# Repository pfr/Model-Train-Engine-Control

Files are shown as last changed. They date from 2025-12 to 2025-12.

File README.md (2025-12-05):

# Model-Train-Engine-Control
If you're a DIYer who enjoys model trains and hobbiest level electronics, and would like to convert your model train engines to radio control and battery power, then this material is for you.

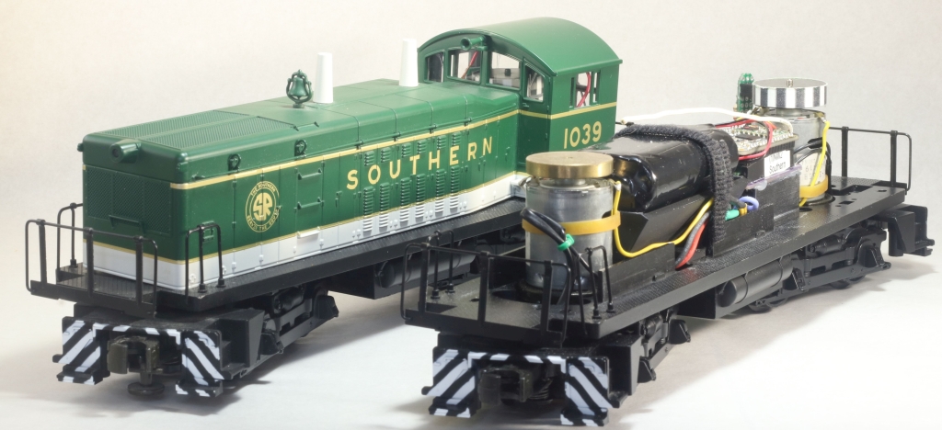
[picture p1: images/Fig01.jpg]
.

Code and other material here was created by me to convert my O scale engines to radio control and battery power.  Seen above is a 1999 MTH NW-2 (https://www.mthtrains.com/products/30-2157-1), one of my smaller engines, with control logic I created and LiPo battery power that can run the engine for hours.  With this accomplishment I'm certain the remainder of my O scale engines can be converted similarly.  There's enough information here to support your doing the same kind of conversions: all of my supporting code, KiCAD design files for a custom PCB, and FreeCAD  design files for 3D printed parts.  

An article on this effort will appear in an upcoming issue of Model Railroader Magazine (https://www.trains.com/mrr/) in early 2026. 

2025 12 05: A reasonably detailed instruction manual for the material here will follow soon.

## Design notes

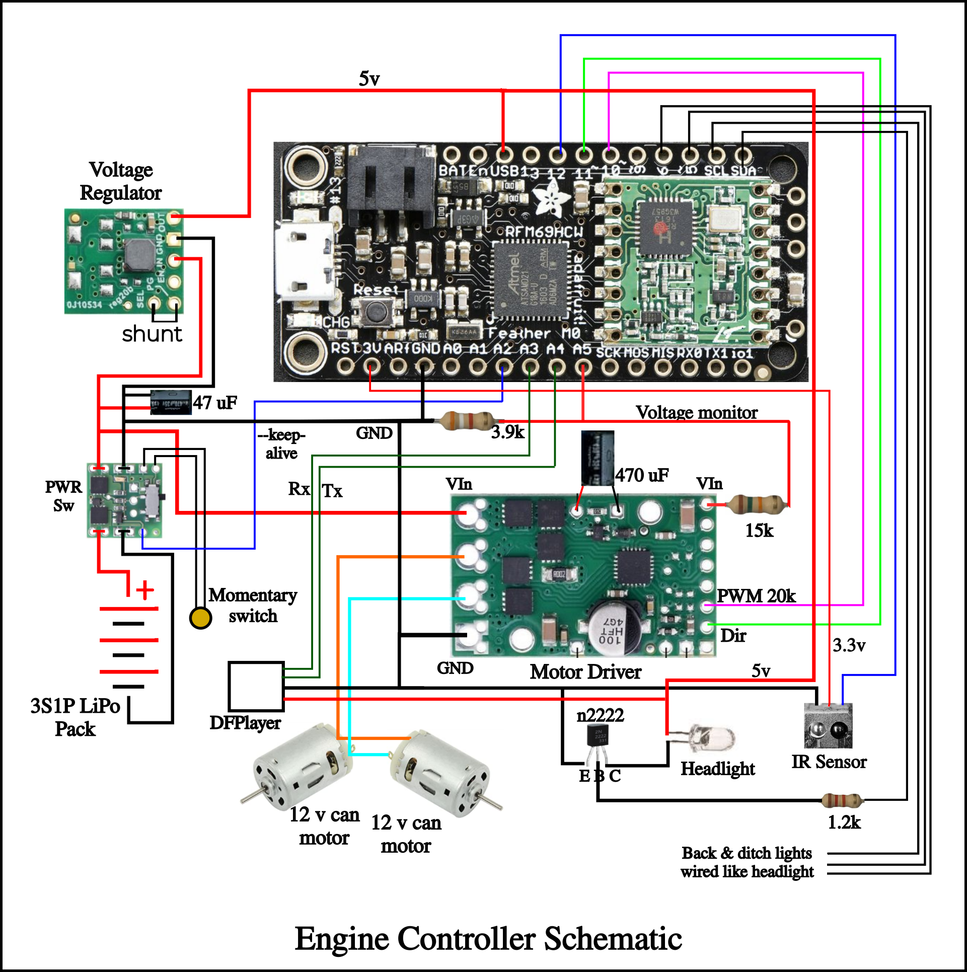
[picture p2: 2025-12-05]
EngineControlSchematic/schematic_20251204_1220.png

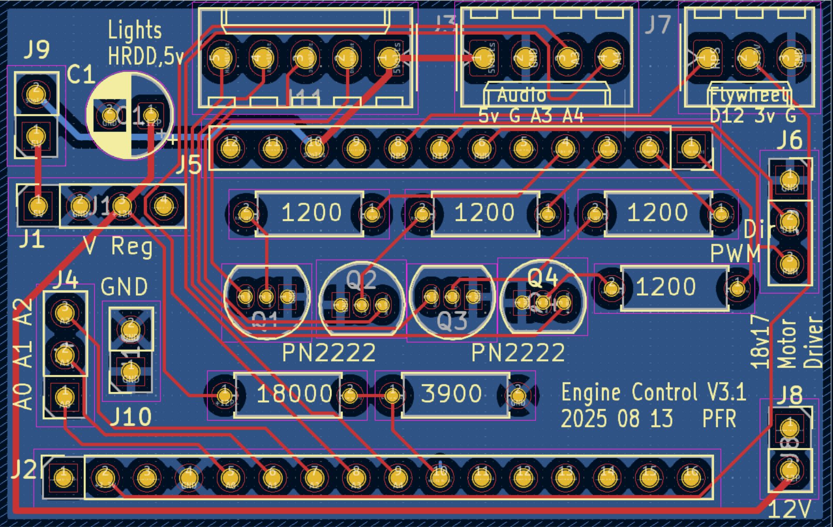
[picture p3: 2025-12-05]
Engine_controller_PCB/PCB_2025_08_13.jpg

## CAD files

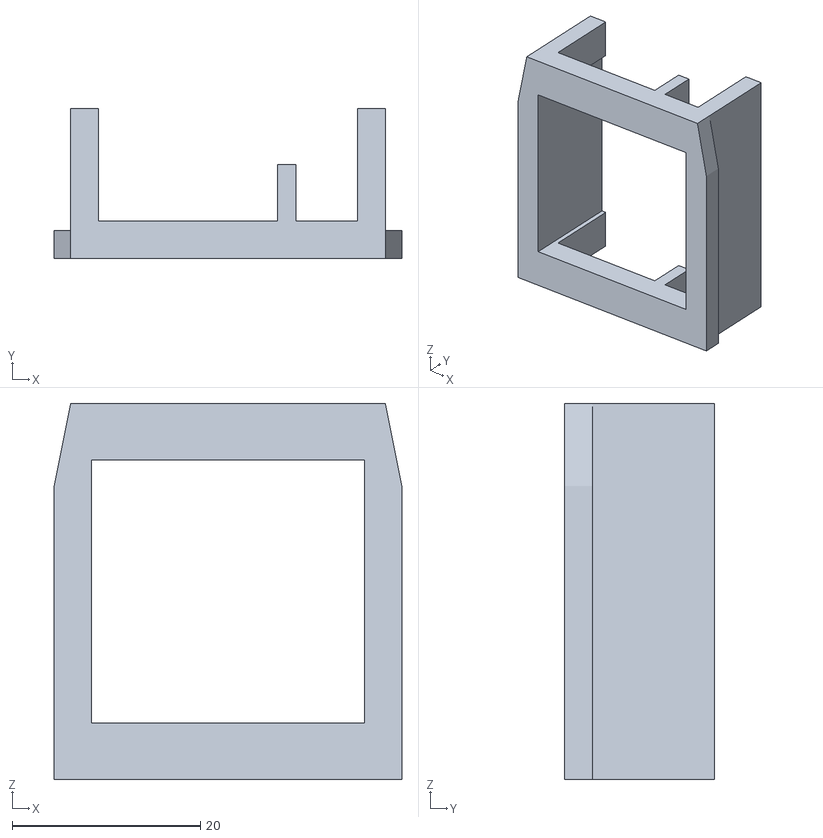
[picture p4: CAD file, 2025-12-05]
3D_parts/NW-2_prints/Electronics_Support_v3-Body.stl
37.0 x 16.0 x 40.0

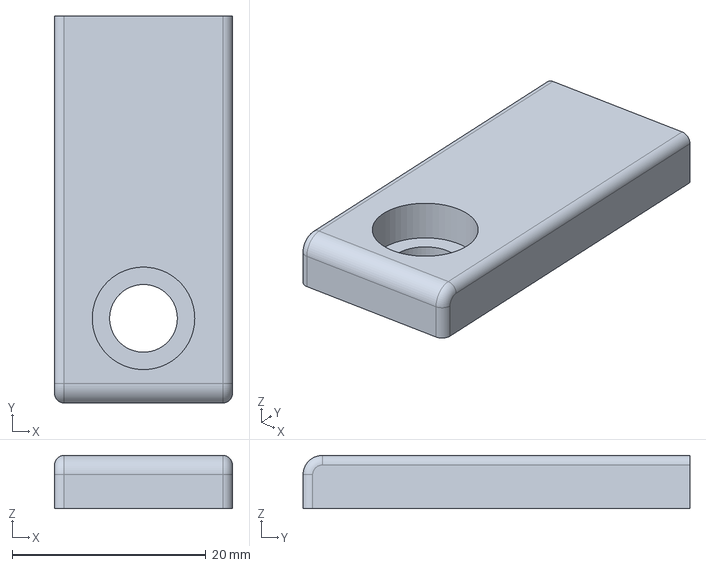
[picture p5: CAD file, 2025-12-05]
3D_parts/NW-2_prints/chargingport_V3.FCStd
18.4 x 40.0 x 5.50 mm

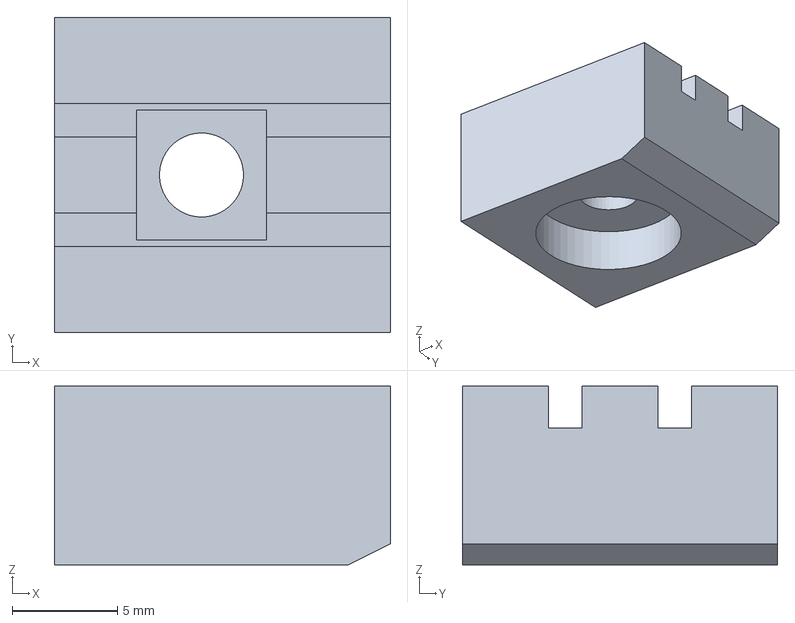
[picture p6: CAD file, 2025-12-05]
3D_parts/NW-2_prints/startSwitchBody.FCStd
16.0 x 15.0 x 8.50 mm

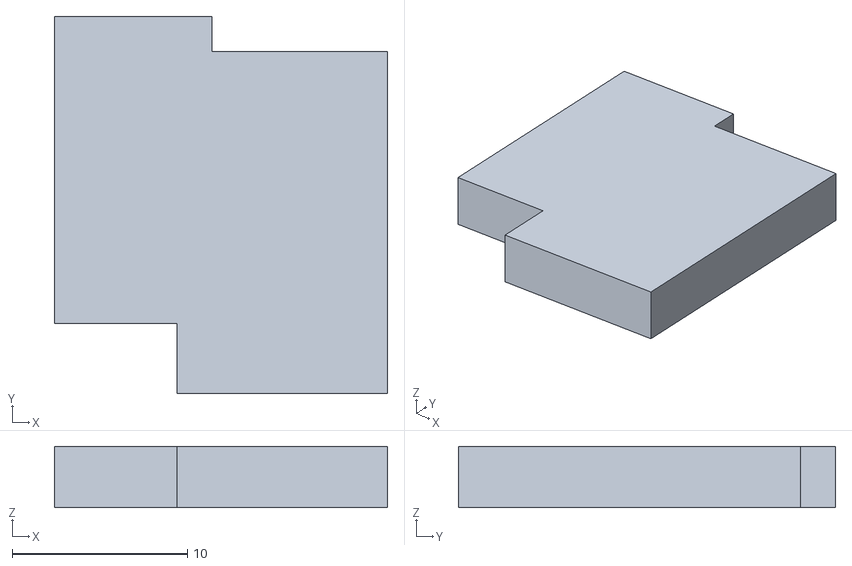
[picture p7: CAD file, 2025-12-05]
3D_parts/NW-2_prints/controlSupportFiller_V2-Body.stl
19.0 x 21.5 x 3.50

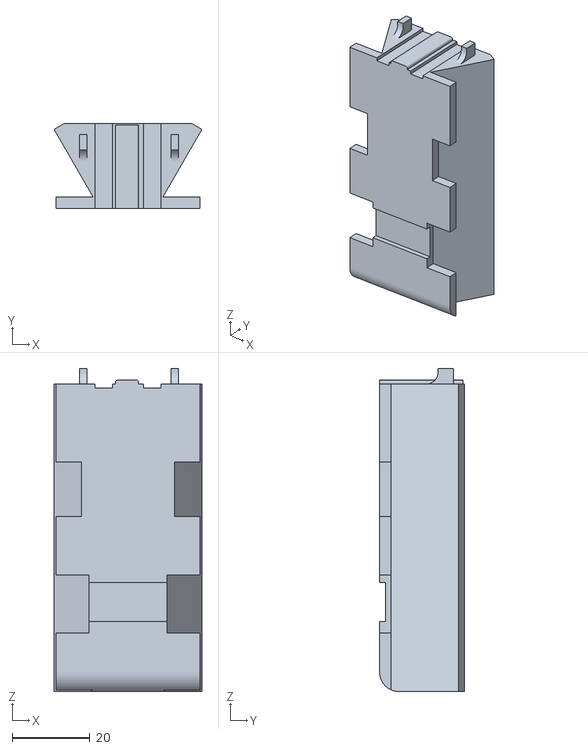
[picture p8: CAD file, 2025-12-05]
3D_parts/NW-2_prints/batterySupport_V12-Body.stl
38.0 x 21.8 x 83.0

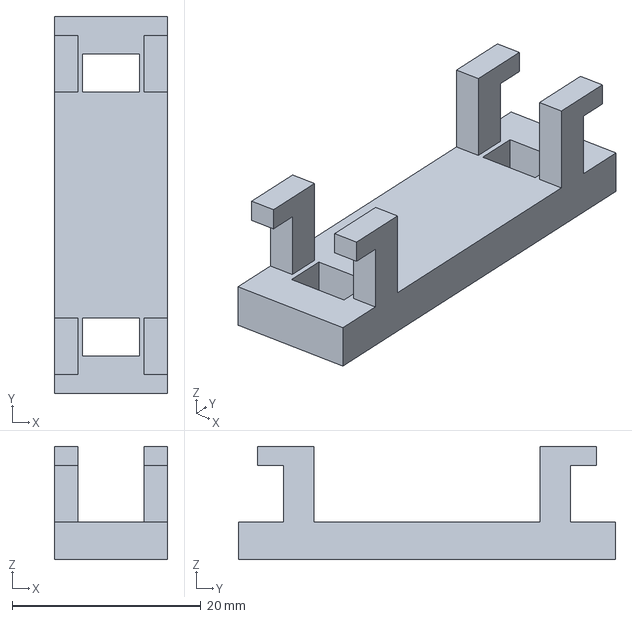
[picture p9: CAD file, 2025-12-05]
3D_parts/NW-2_prints/tieDown.FCStd_V2.FCStd
12.0 x 40.0 x 12.0 mm

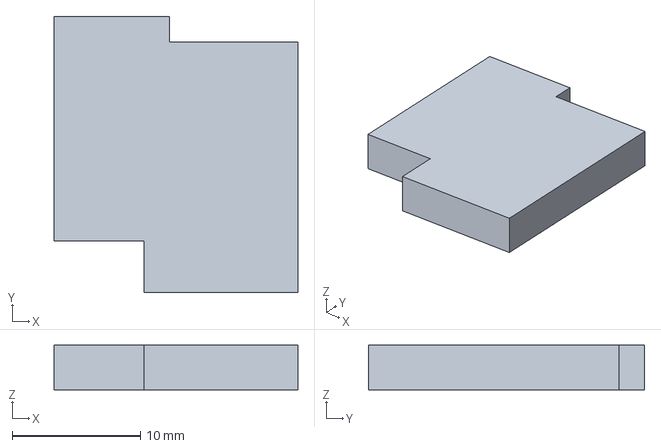
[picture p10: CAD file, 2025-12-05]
3D_parts/NW-2_prints/controlSupportFiller_V2.FCStd
19.0 x 21.5 x 3.50 mm

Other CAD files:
3D_parts/NW-2_prints/batterySupport_V12.FCStd
3D_parts/NW-2_prints/Electronics_Support_v3.FCStd
3D_parts/NW-2_prints/tieDown.FCStd_V2-Body.stl
3D_parts/NW-2_prints/startSwitchBody-Body.stl
3D_parts/NW-2_prints/chargingport_V3-Body.stl

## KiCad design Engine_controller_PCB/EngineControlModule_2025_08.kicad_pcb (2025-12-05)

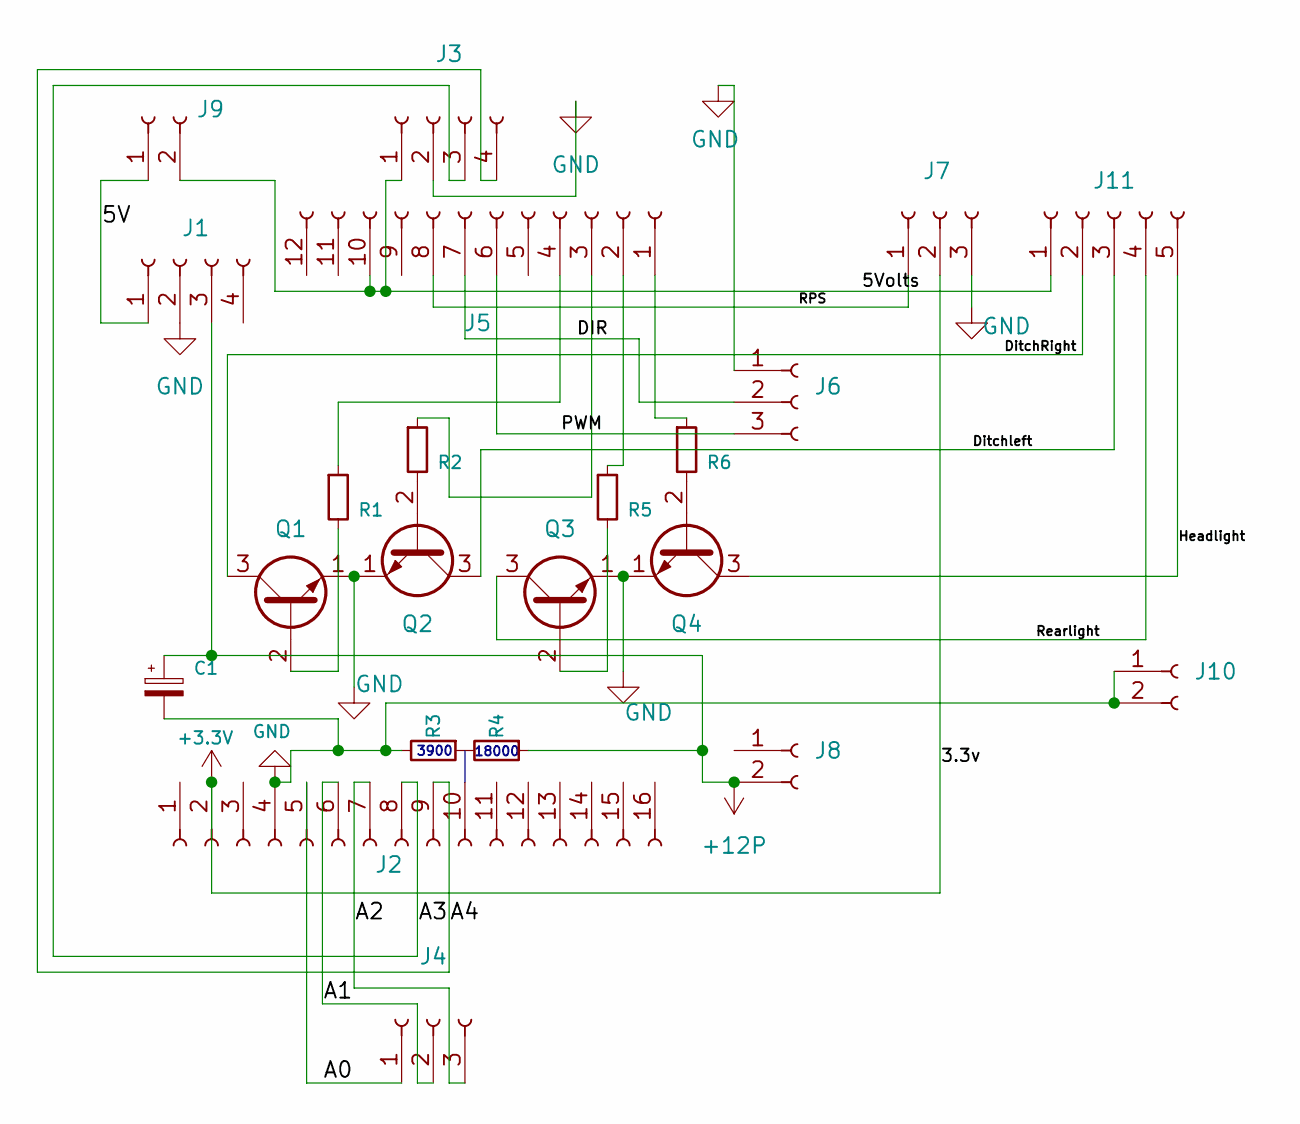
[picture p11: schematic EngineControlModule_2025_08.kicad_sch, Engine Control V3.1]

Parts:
C1: C_Polarized_Small; CP_Radial_D5.0mm_P2.50mm
J1: Conn_01x04_Socket; PinSocket_1x04_P2.54mm_Vertical
J2: Conn_01x16_Socket; PinSocket_1x16_P2.54mm_Vertical
J3: Conn_01x04_Socket; Molex_KK-254_AE-6410-04A_1x04_P2.54mm_Vertical
J4, J6: Conn_01x03_Socket; PinSocket_1x03_P2.54mm_Vertical
J5: Conn_01x12_Socket; PinSocket_1x12_P2.54mm_Vertical
J7: Conn_01x03_Socket; Molex_KK-254_AE-6410-03A_1x03_P2.54mm_Vertical
J8, J9, J10: Conn_01x02_Socket; PinSocket_1x02_P2.54mm_Vertical
J11: Conn_01x05_Socket; Molex_KK-254_AE-6410-05A_1x05_P2.54mm_Vertical
Q1, Q2, Q3, Q4: PN2222A; TO-92_Inline
R1, R2, R3, R4, R5, R6: R_Small; R_Axial_DIN0207_L6.3mm_D2.5mm_P7.62mm_Horizontal

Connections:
+3.3V: J2.2, J7.2
+12P: C1.1, J1.3, J8.2, R4.1
/5V: J1.1, J9.1
/5Volts: J3.1, J5.10, J9.2, J11.1
/A0: J2.5, J4.1
/A1: J2.6, J4.2
/A2: J2.7, J4.3
/A3: J2.8, J3.3
/A4: J2.9, J3.4
/DIR: J5.7, J6.2
/DitchRight: J11.2, Q1.3 (C)
/Ditchleft: J11.3, Q2.3 (C)
/Headlight: J11.5, Q4.3 (C)
/PWM: J5.6, J6.3
/RPS: J5.8, J7.1
/Rearlight: J11.4, Q3.3 (C)
GND: C1.2, J1.2, J2.4, J3.2, J6.1, J7.3, J10.1, J10.2, Q1.1 (E), Q2.1 (E), Q3.1 (E), Q4.1 (E), R3.2
unnamed: J5.1, R6.1
unnamed: J5.2, R5.1
unnamed: J5.3, R2.1
unnamed: J5.4, R1.1
unnamed: Q1.2 (B), R1.2
unnamed: Q2.2 (B), R2.2
unnamed: Q3.2 (B), R5.2
unnamed: Q4.2 (B), R6.2

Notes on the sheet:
3900
18000

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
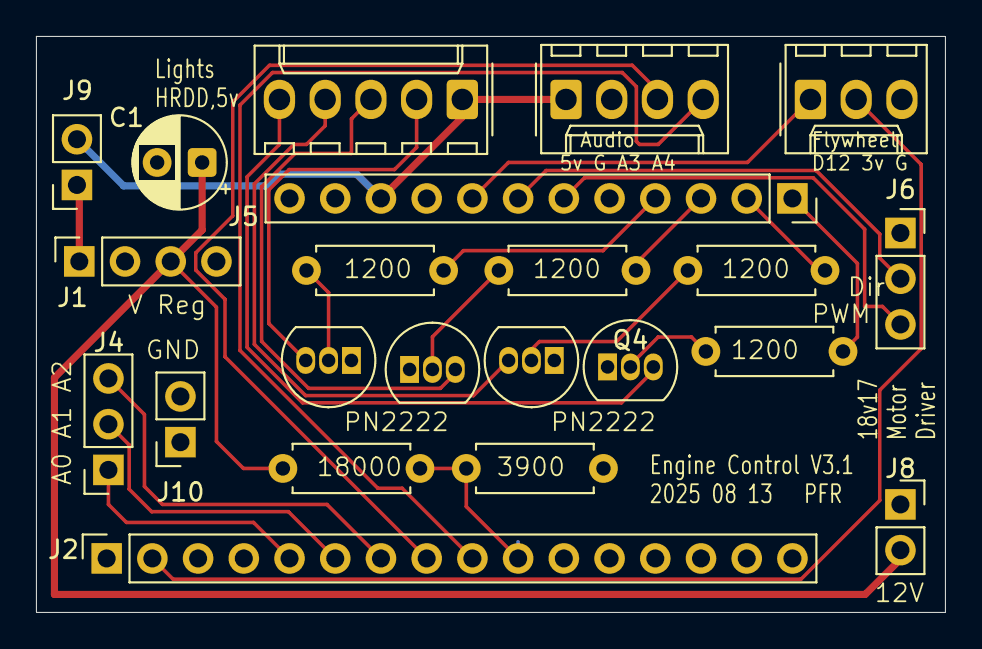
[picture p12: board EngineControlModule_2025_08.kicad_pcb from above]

Board: 2 copper layers, 50.5 x 32.0 mm, 22 parts (0 on the bottom side), 26 nets.

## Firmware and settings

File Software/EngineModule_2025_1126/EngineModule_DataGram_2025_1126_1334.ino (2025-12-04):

  //
//   last updated  2025 11 26
//     Added provisions for responding to a total reset request from engineMaster
//     Added desRPS and smoothedRPS to parameter list for sendStatus
//     Set up information messages for higher levels
//     Added pullup for pin 12 (argh, 1.5 days lost on that one)
//     Fixed estimated speed computation for cruise mode;  fixed head/rear lights issue
//     Add update cruise RPS values on the fly.
//     Add provisions for detecting and reporting dead battery
//     Got reset working better, as well as management of myEngines
//     Modified for streamlined engineConduit API; added smoothing for read battery voltage
//     Added provision for parameterized low voltage cutoff, since different control boards use different divider networks.
//     Updated low voltage cutoff and smoothedVoltage initial values to avoid false triggering.
//     Modified timeout for hearing back from conduit for reg ACK to six seconds (formerly two).
//     2025 11 24: Added provisions for cutting off battery power, detected locally or commanded from external.
//     2025 11 26: Made powering off a loop that drops A2 once per second;  should depower processor quickly and reliably.
//                 Also repaired power-off issues entangled with issue with boolean state info.
//                 Also tightened up takeAction code error processing.
//
//  Code for Feather with onboard RF69 433MHz packet radio and connections to Pololu motor *driver* (not controller).  This code sets up packet radio
//  and PWM for driving motor driver, and then loops, receiving commands via packet radio, ACking them, and then applying received commands to motor(s).
//  Code also tracks flywheel revolutions in order to apply cruise control.
//   Pin use:
//     Power comes in USB 5 volt port.  DO NOT ATTACH TO USB WHEN ALTERNATE POWER SOURCE IS ENABLED
//     Pin 10:  Output.  20 kHz PWM for motor driver board.
//     Pin 11:  Output.  Direction controller for motor driver board.
//     Pin 12:  Input.  Tracks pulses off IR sensor.  Periodic interrupts capture counts for program.
//     Pins A1-A4: Output.  Engine lights control.  (Or D20, D21, D5 and D6 on newer designs)
//     Pin A5:  Input.  Read Battery voltage indicator.
//
//  Radio input is of the form:
//    byte 0:  command to respond to
//    byte 1ff:  binary data may follow if operation in byte 0 needs it, e.g. for a speed command.  Speed value is one byte, zero to 100.



#include <SPI.h>    // for comms with packet radio
#include <RH_RF69.h>   // Packet radio library 
#include <RHReliableDatagram.h>
#include "defines.h"

// myAddress is temporarily set to 254 for signaling a request for a fixed datagram address
#define serverAddress 250
uint8_t myAddress = 254;

#define reverse 1
#define forward 2
#define dirUnknown 0

#define percent 1
#define cruise 2
#define unknown 0

//   StatusReportFreq is multiples of TCC2 interrupt frequency
#define statusReportFreq 2

int resolution = 2400;   //  Related to duty cycle.  Equals (48MHz clock speed / PWM frequency).

bool startedUp = false;         //  True iff engine has been started up.
bool shuttingDown = false;      // True if shutdown requested and speed still > 0.
uint8_t  engineDirection = dirUnknown; 
uint8_t smoothedVoltage = 190;     // RC filtered(1/2, 1/2) voltage of LiPo battery.  190 is over all known cutoffs
uint8_t lowVoltageCutoff = 167;    // This value is sent to engine on startup.  Typ value is 168 or 177 depending on
                                   // divider network used on control board.  167 is a failsafe placeholder.
uint8_t flash = 0;             // For toggling onboard LED to show life
uint8_t ditchLightToggle = 1;  // used to alternate between left and right ditch lights
uint8_t statusReportCounter = statusReportFreq;  // Used to determine status report frequency (based on TCC2 ints)
bool beenToldToRestart = true;
int lowVoltageCount = 0;   //  Keeps track of repeated low voltage readings in support of power off conditions.
bool lowVoltage = false;  // Once low voltage has been seen often enough, this gets set in order to trigger shutdown/power off
bool beenToldToPowerDown = false;  //  If command setPowerToOff arrives then this gets set true and power should be cut.

int headlight;
int rearlight;
int leftDitch;
int rightDitch;

  union
  {
    uint16_t onePiece;
    uint8_t twoPieces[2];
  }myEngineNumber;  // Low order two bytes of CPUNumber


uint8_t speedControlMethod = unknown;  
bool DEBUG = false;

void TCC2_Handler();  // Prototype for one second interrupts handler



  RH_RF69 rf69(8, 3); // Adafruit Feather M0  CS and INT pins for RFM69 radio
  RHReliableDatagram manager(rf69, myAddress);  // Set up with temporary address

void setup() {
  pinMode(LED_BUILTIN, OUTPUT);  // Built in LED
  pinMode(A5, INPUT);  // Battery voltage monitoring pin;  12.6 volts should show up as 2.74 volts; about 840 out of 1023.
  #define dirPin 11
  pinMode(dirPin, OUTPUT);  // Connect to Dir input on Pololu motor driver.  (Pin 11 on M0)
  // Pin D10 is output used for PWM
  // Pin D12 is input used for cruise control (count pulses off IR sensor tracking flywheel strip)
  pinMode(12, INPUT_PULLUP);
  pinMode(A2, OUTPUT);   // Alive pin for soft power switch.  Keep high unless power off is requested or required.
  digitalWrite(A2, HIGH); 

  ////////////////////////////////////////////////////////////////////////////////////////
  // Generic Clock Initialisation 
  ////////////////////////////////////////////////////////////////////////////////////////

// Set up 32kHz clock for 1 Hz interrupts
  GCLK->GENDIV.reg =  GCLK_GENDIV_DIV(1) |          // Select clock divisor to 1                     
                      GCLK_GENDIV_ID(4);            // Select GLCK4         
 
  GCLK->GENCTRL.reg = GCLK_GENCTRL_IDC |            // Set the duty cycle to 50/50 HIGH/LOW 
                      GCLK_GENCTRL_GENEN |          // Enable GCLK                   
                      GCLK_GENCTRL_SRC_XOSC32K |    // Select GCLK source as external 32.768kHz crystal (XOSC32K)                          
                      GCLK_GENCTRL_ID(4);           // Select GCLK4             
  while (GCLK->STATUS.bit.SYNCBUSY);                // Wait for synchronization

  GCLK->CLKCTRL.reg = GCLK_CLKCTRL_CLKEN |         // Enable GCLK0
      GCLK_CLKCTRL_GEN_GCLK0 |                     // Select GCLK0 at 48MHz
      GCLK_CLKCTRL_ID_TCC0_TCC1;                   // Connect GCLK0 to timers TCC0 and TCC1
    while (GCLK->STATUS.bit.SYNCBUSY);             // Wait for synchronization

  GCLK->CLKCTRL.reg = GCLK_CLKCTRL_CLKEN |          // Enable generic clock
                      GCLK_CLKCTRL_GEN_GCLK0 |      // GCLK0 at 48MHz 
                      GCLK_CLKCTRL_ID_TC4_TC5;      // As a clock source for TC4 and TC5
  
  GCLK->CLKCTRL.reg = GCLK_CLKCTRL_CLKEN |          // Enable generic clock
                      GCLK_CLKCTRL_GEN_GCLK4 |      // GCLK4 at 32.768kHz
                      GCLK_CLKCTRL_ID_TCC2_TC3;     // As a clock source for TCC2 and TC3
//    while (GCLK->STATUS.bit.SYNCBUSY);             // Wait for synchronization


  PM->APBCMASK.reg |= PM_APBCMASK_EVSYS;           // Switch on the event system peripheral
  
//    ********************************************************************** P W M   S e t u p *************************************
// SAMD21G timers
//        GCLK_CLKCTRL_ID(GCM_TCC0_TCC1), // TCC0
//        GCLK_CLKCTRL_ID(GCM_TCC0_TCC1), // TCC1
//        GCLK_CLKCTRL_ID(GCM_TCC2_TC3),  // TCC2
//        GCLK_CLKCTRL_ID(GCM_TCC2_TC3),  // TC3
//        GCLK_CLKCTRL_ID(GCM_TC4_TC5),   // TC4
//        GCLK_CLKCTRL_ID(GCM_TC4_TC5),   // TC5

  //////////////////////////////////////////////////////////////////////////////////////////////
// Set-up TCC0 and TCC1 for 20kHz PWM, 0% duty-cycle (initially) on digital pin 10  pin 10    pin 10   pin 10
// Pin 10 is used for motoer speed control by controlling duty cycle on its 20kHz signal
  //////////////////////////////////////////////////////////////////////////////////////////////
//
  // Enable the port multiplexer for the PWM channel for digital pin 10
  PORT->Group[g_APinDescription[10].ulPort].PINCFG[g_APinDescription[10].ulPin].bit.PMUXEN = 1; 
  // Connect the TCC0 channel 2 to digital pin 10
  PORT->Group[g_APinDescription[10].ulPort].PMUX[g_APinDescription[10].ulPin >> 1].reg |= PORT_PMUX_PMUXE_F;
  TCC0->WAVE.reg = TCC_WAVE_WAVEGEN_NPWM;        // Set the PWM output to dual-slope critical PWM mode
    while (TCC0->SYNCBUSY.bit.WAVE);             // Wait for synchronization
  TCC0->PER.reg = (resolution - 1);              // Set the frequency of the PWM to 20kHz ((48MHz/20kHz)-1) on D9
    while (TCC0->SYNCBUSY.bit.PER);              // Wait for synchronization
    TCC0->CC[2].reg = 0;                         // Set the duty-cycle to 0%
    while (TCC0->SYNCBUSY.bit.CC2);              // Wait for synchronization
  TCC0->CTRLA.bit.ENABLE = 1;                    // Enable the TCC0 timer
    while (TCC0->SYNCBUSY.bit.ENABLE);           // Wait for synchronization

  
  //////////////////////////////////////////////////////////////////////////////////////////////
  // TCC2 Initialisation - reference timer: measures a 1s period and generates an interrupt.
  //////////////////////////////////////////////////////////////////////////////////////////////     
  
  TCC2->PER.reg = 32767;           //Timer-Frequency = Generic-Clock-Frequency / (Timer-Prescaler * (Value-PER-Register + 1))
    while(TCC2->SYNCBUSY.bit.PER);
  TCC2->WAVE.reg |= TCC_WAVE_WAVEGEN_NPWM;     //Set up normal PWM mode on TCC2
    while (TCC2->SYNCBUSY.bit.WAVE);
  TCC2->CC[0].reg = 16384;       //Set CounterCompare.
    while(TCC2->SYNCBUSY.bit.CC0);
  TCC2->INTENSET.reg = TCC_INTENSET_OVF;     //Enable TCC2 OVF Interrupt
  TCC2->CTRLA.bit.ENABLE = 1;           //Enable timer TCC2 and wait for synchronization
    while (TCC2->SYNCBUSY.bit.ENABLE);
  NVIC_SetPriority(TCC2_IRQn, 15);    //Set NVIC priority for TCC2 to 15 (lowest)
  NVIC_EnableIRQ(TCC2_IRQn);      //Connect TCC2 to Nested Vector Interrupt Controller (NVIC)


  ////////////////////////////////////////////////////////////////////////////////////////
  // TC4 Initialisation - measurement counter: counts the number incoming pulses on pin D12
  ////////////////////////////////////////////////////////////////////////////////////////
  
  // Enable the port multiplexer on digital pin D12 (port pin PA19)
  PORT->Group[g_APinDescription[12].ulPort].PINCFG[g_APinDescription[12].ulPin].bit.PMUXEN = 1;
  // Set-up the pin as an EIC (interrupt) peripheral on D12
  PORT->Group[g_APinDescription[12].ulPort].PMUX[g_APinDescription[12].ulPin >> 1].reg |= PORT_PMUX_PMUXO_A;

  // External Interrupt Controller (EIC) ///////////////////////////////////////////////////

  EIC->EVCTRL.reg |= EIC_EVCTRL_EXTINTEO3;                                // Enable event output on external interrupt 3 (D12)
  EIC->CONFIG[0].reg |= EIC_CONFIG_SENSE3_HIGH;                           // Set event detecting a HIGH level on interrupt 3
  EIC->INTENCLR.reg = EIC_INTENCLR_EXTINT3;                               // Disable interrupts on interrupt 3
  EIC->CTRL.bit.ENABLE = 1;                                               // Enable the EIC peripheral
  while (EIC->STATUS.bit.SYNCBUSY);                                       // Wait for synchronization

  // Event System //////////////////////////////////////////////////////////////////////////

  EVSYS->USER.reg = EVSYS_USER_CHANNEL(1) |                               // Attach the event user (receiver) to channel 0 (n + 1)
                    EVSYS_USER_USER(EVSYS_ID_USER_TC4_EVU);               // Set the event user (receiver) as timer TC4
  EVSYS->CHANNEL.reg = EVSYS_CHANNEL_EDGSEL_NO_EVT_OUTPUT |               // No event edge detection
                       EVSYS_CHANNEL_PATH_ASYNCHRONOUS |                  // Set event path as asynchronous
                       EVSYS_CHANNEL_EVGEN(EVSYS_ID_GEN_EIC_EXTINT_3) |   // Set event generator (sender) as external interrupt 3
                       EVSYS_CHANNEL_CHANNEL(0);                          // Attach the generator (sender) to channel 0                                 
  
  // Timer Counter TC4 /////////////////////////////////////////////////////////////////////

  TC4->COUNT32.EVCTRL.reg |= TC_EVCTRL_TCEI |              // Enable asynchronous events on the TC timer
                             TC_EVCTRL_EVACT_COUNT;        // Increment the TC timer each time an event is received
  TC4->COUNT32.CTRLA.reg = TC_CTRLA_MODE_COUNT32;          // Configure TC4 together with TC5 to operate in 32-bit mode
  TC4->COUNT32.CTRLA.bit.ENABLE = 1;                       // Enable TC4
    while (TC4->COUNT32.STATUS.bit.SYNCBUSY);                // Wait for synchronization
  TC4->COUNT32.READREQ.reg = TC_READREQ_RCONT |            // Enable a continuous read request
                             TC_READREQ_ADDR(0x10);        // Offset of the 32-bit COUNT register
    while (TC4->COUNT32.STATUS.bit.SYNCBUSY);                // Wait for synchronization
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
void loop() {
  uint8_t buf[RH_RF69_MAX_MESSAGE_LEN];
  uint8_t len = sizeof(buf);
  uint8_t from;

  if (timerInterrupt){ // TCC2 one second interrupt handler was called, (and perhaps pulse counter on D12 collected.)
	  timerInterrupt = false;   //  Clear one second interrupt (TCC2) flag;

    if (!DEBUG and (lowVoltage && not beenToldToPowerDown)){
      buf[1] = myAddress;   
      buf[0] = shutDownEngine;             // Initiate shutdown
      takeAction(buf, 2);  
      beenToldToPowerDown = true;     //  Trigger eventual power off after shutdown
    }

  // Is it time for a status report?
	  if (statusReportCounter >0)
		  statusReportCounter--;  // Ticking down to send time
      else { // Yes, time to issue a status report
        statusReportCounter = statusReportFreq;
          // Special case status report when power is low...
          //////  These messages will only be sent until engine power is ultimately cut off
        if (lowVoltage || beenToldToPowerDown){
          buf[1] = myAddress;   
          buf[0] = engineModuleInformation;
          buf[2] = batteryProtectionMode;
          buf[3] = smoothedVoltage;
          sendToMaster(buf, 4);
        }
              // send normal status report
        if (speedControlMethod == percent)
            sendStatus(engineDirection, speedControlMethod, currentPercentage, smoothedVoltage, 0, smoothedRPS);
        else if(speedControlMethod == cruise)
            sendStatus(engineDirection, speedControlMethod, speedFromRPS(), smoothedVoltage, desiredRPS, smoothedRPS);
          else  // speedControlMethod is unknown ... not set yet.
            sendStatus(engineDirection, speedControlMethod, 0, smoothedVoltage, 0, smoothedRPS);
      }

    if(startedUp){  // Startup being true ensures engiineDirection is forward or reverse
      if(currentPercentage == 0){  
        digitalWrite(dirPin, engineDirection == forward);  // Set direction pin on motor driver; this action is idempotent;
        digitalWrite(headlight, engineDirection == forward);  // Set headlights according to
        digitalWrite(rearlight, engineDirection == reverse);  // engine direction.
        digitalWrite(leftDitch, LOW);  // At zero motion, ditch lights
        digitalWrite(rightDitch, LOW);  //   should be off.
      }
      else 
        if (engineDirection == forward){  // non-zero forward motion -> ditch lights operating
          digitalWrite(leftDitch, ditchLightToggle);  // Toggle
          digitalWrite(rightDitch, 1-ditchLightToggle);  // ditch lights
          ditchLightToggle = 1-ditchLightToggle;
        }
      // Modify motor power settings to establish desired power/speed outcomes.  percent and cruise are only
            // possibilities since unknown was captured above.
      if (speedControlMethod == percent) updatePercentSetting();
      else if (speedControlMethod == cruise ) updateSpeedSetting();
      } // End, if started up  
                  
    if(startedUp && shuttingDown && (currentPercentage == 0) ) {  // Time for going into shutdown state?
      startedUp = false;      // Together define
      shuttingDown = false;   // shutdown state
      engineDirection = dirUnknown;
      digitalWrite(headlight, LOW);  // Turn off headlight forward
      digitalWrite(rearlight, LOW);  // Turn off headlight reverse
      digitalWrite(leftDitch, LOW);  // At zero speed, ditch lights
      digitalWrite(rightDitch, LOW);  //   should be off.
      if (speedControlMethod == percent)
          sendStatus(engineDirection, speedControlMethod, currentPercentage, smoothedVoltage, 0, smoothedRPS);
      else 
          sendStatus(engineDirection, speedControlMethod, speedFromRPS(), smoothedVoltage, desiredRPS, smoothedRPS);
    }

  } // End timer interrupt based reactions.

  
    if ((beenToldToRestart || beenToldToPowerDown) && !startedUp && !shuttingDown && (currentPercentage == 0)){
      if (beenToldToRestart){
          if (DEBUG) Serial.println(" Been told to restart.");
          speedControlMethod = unknown;
          getRadioDataGramAddress();
      }
      else if (beenToldToPowerDown){  // Engine idle and been told to cut power off
          if (DEBUG) Serial.println(" Been told to power down.");
          while(1){
            digitalWrite(A2, LOW);  // This should shut everything down at soft switch.
            delay(1000);
          }
      }
    }
    else  // Look for a new command from engineMaster
      if (manager.recvfromAckTimeout(buf, &len, 400, &from)){   // New msg has come in
          if(DEBUG){
            Serial.print("\ngot message: [");  Serial.print(buf[0]);   Serial.print("] " ); Serial.print(myAddress);
            Serial.print(";\t\tLast RSSI: ");
            Serial.println(rf69.lastRssi(), DEC);
          }
          if(buf[0] == engineReset || buf[0] == resetAll){
            if(not beenToldToPowerDown){
              buf[0] = shutDownEngine;             // Initiate shutdown before doing reset
              buf[1] = myAddress;
              takeAction(buf, 2);  // After this the engine may still be started up, but shutting down will be true for sure.
            }
            beenToldToRestart = true;   // This will lead to resetting engine module to initial state;
          }

          if(buf[0] == setPowerToOff){  // higher level control is commanding power off conditions.
              buf[0] = shutDownEngine;             // Initiate shutdown
              buf[1] = myAddress;
              takeAction(buf, 2);  // After this the engine may still be started up, but shutting down will be true for sure.
              beenToldToPowerDown = true; // Eventually leads to alive pin (A2) being set low
          }
          else takeAction(buf, len);  //  Most commands coming from engineConduit will be acted on here.
      }
  
}  // loop








//  Useful online comments about interrupts and timers

// 2025 04 24 Martin L code (well known Arduino commenter)
//  


//     Can I put D12 on D6? (D2..D9, A0..A5) would be free. The pin probably works with other interrupts, channels, EIC etc.
//  I am not familiar with the settings. What changes do I have to make?  
//     Yes, it's possible to route any interrupt pin
// through to any timer, via the event system.   The information for what interrupt channel to use can be found from
// Arduino Zero schematic and the SAMD21's Port Multiplexing table in section 7.

// From the schematic (on sheet 2) it's possible to find the port pin for D6, it PA20.
// In the port multiplexing table, row PA20, column A, the external interrupt is on channel 4: EXTINT[4]. As PA20 is
// an even port pin, we select the multiplexer switch for position A (EIC) on the even port: PORT_PMUX_PMUXE_A.

// Just change the following lines of code and the input should work on D6:

  // PORT->Group[PORTA].PINCFG[20].bit.PMUXEN = 1;                            // Enable the port multiplexer on port pin PA20 (D6)
  // PORT->Group[PORTA].PMUX[20 >> 1].reg |= PORT_PMUX_PMUXE_A;               // Set-up PA20 (D6) as an EIC (interrupt)
 
  // EIC->EVCTRL.reg |= EIC_EVCTRL_EXTINTEO4;                                 // Enable event output on external interrupt 4
  // EIC->CONFIG[0].reg |= EIC_CONFIG_SENSE4_HIGH;                            // Set event detecting a HIGH level
  // EIC->INTENCLR.reg = EIC_INTENCLR_EXTINT4;                                // Clear the interrupt flag on channel 4
  // EIC->CTRL.bit.ENABLE = 1;                                                // Enable EIC peripheral
  // while (EIC->STATUS.bit.SYNCBUSY);                                        // Wait for synchronization
 
  // EVSYS->USER.reg = EVSYS_USER_CHANNEL(1) |                                // Attach the event user (receiver) to channel 0 (n + 1)
                    // EVSYS_USER_USER(EVSYS_ID_USER_TC4_EVU);                // Set the event user (receiver) as timer TC4 event
                   
  // EVSYS->CHANNEL.reg = EVSYS_CHANNEL_EDGSEL_NO_EVT_OUTPUT |                // No event edge detection
                       // EVSYS_CHANNEL_PATH_ASYNCHRONOUS |                   // Set event path as asynchronous                     
                       // EVSYS_CHANNEL_EVGEN(EVSYS_ID_GEN_EIC_EXTINT_4) |    // Set event generator (sender) as external interrupt 4
                       // EVSYS_CHANNEL_CHANNEL(0); 

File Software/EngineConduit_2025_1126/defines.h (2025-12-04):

// THIS LIST OF COMMANDS MUST BE KEPT CONSISTENT WITH ALL THREE MODULES!
// -->  engineModule, engineConduit and ControlUI
//  2025 08 17


//  engineModule originates these:
#define registerMe 50
#define statusRpt 51
#define engineModuleInformation 53
#define batteryProtectionMode 54
#define schedulingIssue 55
#define unhandledCommand 56
#define speedSettingIssue 57

// engineMaster originates these
#define engineConduitInformation 102
#define eModBadCommand 103
#define radioFailure 104
#define unknownCommand 105


// ControlUI originates these
#define ACKRegistration 151
#define engineReset 152
#define resetAll 153
#define setUpPercent 155
#define setUpCruise 156
#define startUpEngine 157
#define shutDownEngine 158
#define goForward 159
#define goRearward 160
#define motorControl 161
#define updateCruiseValues 162
#define emergencyStop 163
#define setPowerToOff 164

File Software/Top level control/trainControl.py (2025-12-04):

# Last updated 20251126 1430
# Added consideration for different voltage divider networks in different engines for measuring battery voltage
# Engines are now sent an engine specific 8 bit value to use for determining low voltage. (typ 168 or 180,
#  168 is for a 15k upstream resistor in the divider network, and 143 is for 18k.)
#   Added provisions for detecting engines that have stopped sending status reports when they are still
# registered.  They get sent a reset, and are unregistered locally.
#  Added provisions for handling engine reports of low battery; and for this code to tell an engine to
# disconnect from its battery.
# Added processing for additional engineModule error reports.

import tkinter as tk
from tkinter import *
from tkinter import messagebox
from tkinter import scrolledtext
import tkinter.font as font
from datetime import datetime
from PIL import Image, ImageDraw, ImageFont
import time
import sys
import os
import shutil
import socket
import threading
import serial




protectSerial = threading.Lock()
protectInternals = threading.Lock()   # Protect internal data when updating internally and with extern data
DEBUG = True

# # # # # # # # # # # # # # #  E n g i n e M a s t e r   c o m m s   s e t u p       # # # # # # # # # # # # # # #
# #

ENGCom = 'com14'
#ENGCom = '/dev/ttyACM0'  # Expected port on Ubuntu

try:
    ENGPort = serial.Serial(ENGCom,115200)
except:
    ENGCom = ''
    print("No serial connection made.")


registerMe = "50"
statusRpt = "51"
engineModuleInformation = "53"
batteryProtectionMode = "54"
schedulingIssue = "55"
unhandledCommand = "56"
speedSettingIssue = "57"

engineConduitInformation = "102"
eModBadCommand = "103"
radioFailure = "104"
unknownCommand = "105"

ACKRegistration = "151"
engineReset = "152"
resetAll = "153"
setUpPercent = "155"
setUpCruise = "156"
startUpEngine = "157"
shutDownEngine = "158"
goForward = "159"
goRearward = "160"
motorControl = "161"
updateCruiseValues = "162" 
emergencyStop = "163"
setPowerToOff = "164"

noEngine = 255
# # # # # # # # # # # # # # # # # # # #   E n g i n e M a s t e r   l i s t e n e r       # # # # # # # # # # # # # # # #
# #


class ListenToENG (threading.Thread):
  # Receive packets from engineConduit communicating through common ENGPort port.

    def run(Self):
        time.sleep(0.2)  # Let other threads run
        print('engineConduit listening thread started.', flush = True)
        while True:
            protectSerial.acquire()
            if (ENGPort.in_waiting > 0):  # There's something at the com port connected to Engine Feather to read
                fromENG = (ENGPort.readline().decode("utf-8").rstrip('\n\r')).lstrip('\0')
                protectSerial.release()
#                print('\n' + str(datetime.now())[11:-3] + ' Received from EngineConduit: ' + '\'' + fromENG +'\'')

#        Process and respond as needed to any inputs
                splitInput = fromENG.split()
                if splitInput[0] == registerMe:
                    engineSerial = int(splitInput[1])
    #registration
                    print('\n Engine ' + hex(engineSerial) + " registering")
                    index = tc.getIndexFromSerial(engineSerial)
                    if index != noEngine:
                        protectInternals.acquire()
                        tc.refreshEngineData(index, index+1)  # Resets engine data to original state
                        tc.myEngines[index][tc.theObsEngineStateIdx] = tc.REG   # mark engine registered
                        tc.myEngines[index][tc.theSetEngineStateIdx] = tc.REG
                        tc.myEngines[index][tc.timeOutIdx] = time.time()  # Set last status report time
                        protectInternals.release()
                        protectSerial.acquire()
                        ENGPort.write((ACKRegistration + ' ' + str((engineSerial & 0xFF00) >> 8) + " " + str(engineSerial & 0xFF) + " " + str(index) + \
                                        " " +  str(tc.myEngines[index][tc.battCutoffIdx]) + '\n').encode())
                        protectSerial.release()                                        
                        print("Just sent ACKregistration back to engine conduit for " + tc.myEngines[index][tc.theEngineNameIdx])
                        print("Sent: " + ACKRegistration + ' ' + str((engineSerial & 0xFF00) >> 8) + " " + str(engineSerial & 0xFF) + " " + str(index) + \
                                        " " +  str(tc.myEngines[index][tc.battCutoffIdx]) + '\n')
                    else:
                        tc.importantMessage = str(datetime.now())[11:-7] +  " Unknown engine trying to register: " + splitInput[1]
    # Protecting battery and other messages from engine module
                elif splitInput[0] == engineModuleInformation:
                    try:
                        index = int(splitInput[1])
                        engineName = tc.myEngines[index][tc.theEngineNameIdx]
                    except:
                        engineName = "unknown"
                    if engineName != "unknown":
                        print(str(datetime.now())[11:-7] +  " " + fromENG[2:])
                        if splitInput[2] == batteryProtectionMode:
                            tc.importantMessage = str(datetime.now())[11:-7] +  " " + engineName + " Protected battery!"
                            tc.refreshEngineData(index, index+1)  # Resets engine data to original state
                            tc.myEngines[index][tc.batteryBeingProtectedIdx] = True
                        elif splitInput[2] == schedulingIssue:
                            tc.importantMessage = str(datetime.now())[11:-7] +  " " + engineName + " Emod scheduling issue"
                        elif splitInput[2] == speedSettingIssue:
                            tc.importantMessage = str(datetime.now())[11:-7] +  " " + engineName + " Emod speed setting issue"
                        elif splitInput[2] == unhandledCommand:
                            tc.importantMessage = str(datetime.now())[11:-7] +  " " + engineName + " Emod REJECTED COMMAND"    
                        else:
                            tc.importantMessage = str(datetime.now())[11:-7] +  " " + fromENG[2:] + "...UNK mess from eng"
                    else:
                        tc.importantMessage = str(datetime.now())[11:-7] +  " " + fromENG[2:] + "...UNK engine"
    # Reports from engineConduit
                elif splitInput[0] == engineConduitInformation:
                    try:
                        index = int(splitInput[1])
                        engineName = tc.myEngines[index][tc.theEngineNameIdx]
                    except:
                        engineName = "unknown"
                    if engineName != "unknown":                        
                        print(str(datetime.now())[11:-7] +  " " + fromENG[2:])
                        if splitInput[2] == eModBadCommand:
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
